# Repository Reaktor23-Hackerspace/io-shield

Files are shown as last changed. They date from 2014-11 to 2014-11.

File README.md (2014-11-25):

# IO-shield

IO-shield is a Arduino shield with 8 LED's, 8 push buttons and 2 potentiometers, designed for learning purposes.

# Pictures

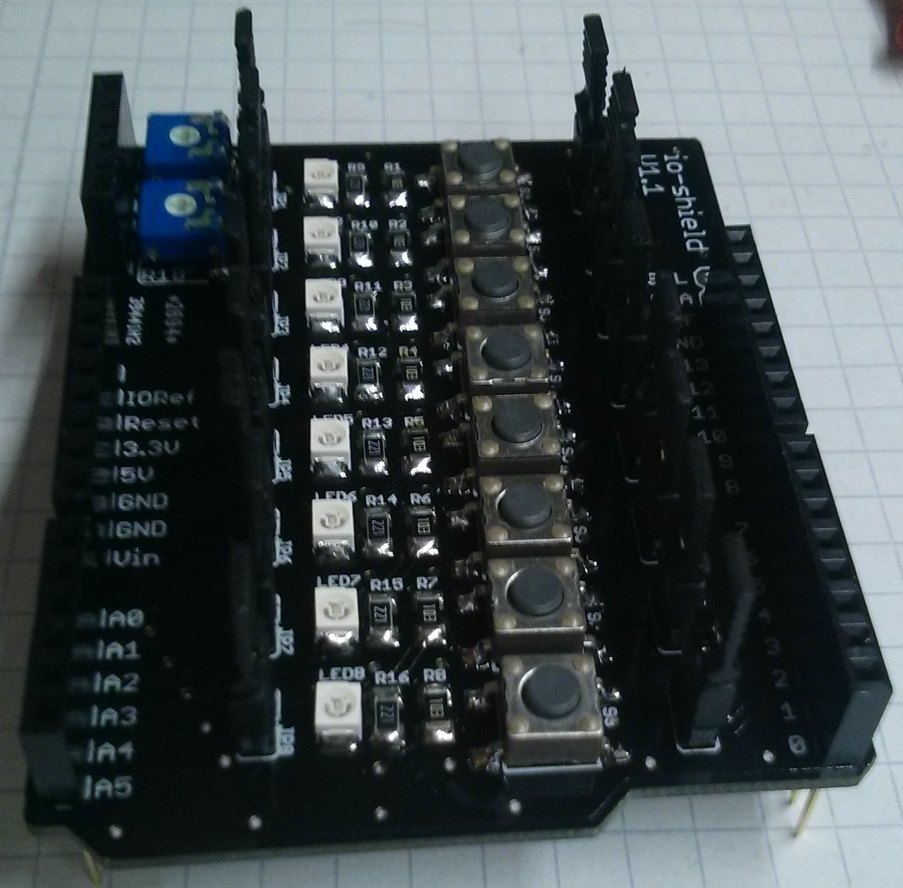
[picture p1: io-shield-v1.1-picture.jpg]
io-shield asambled


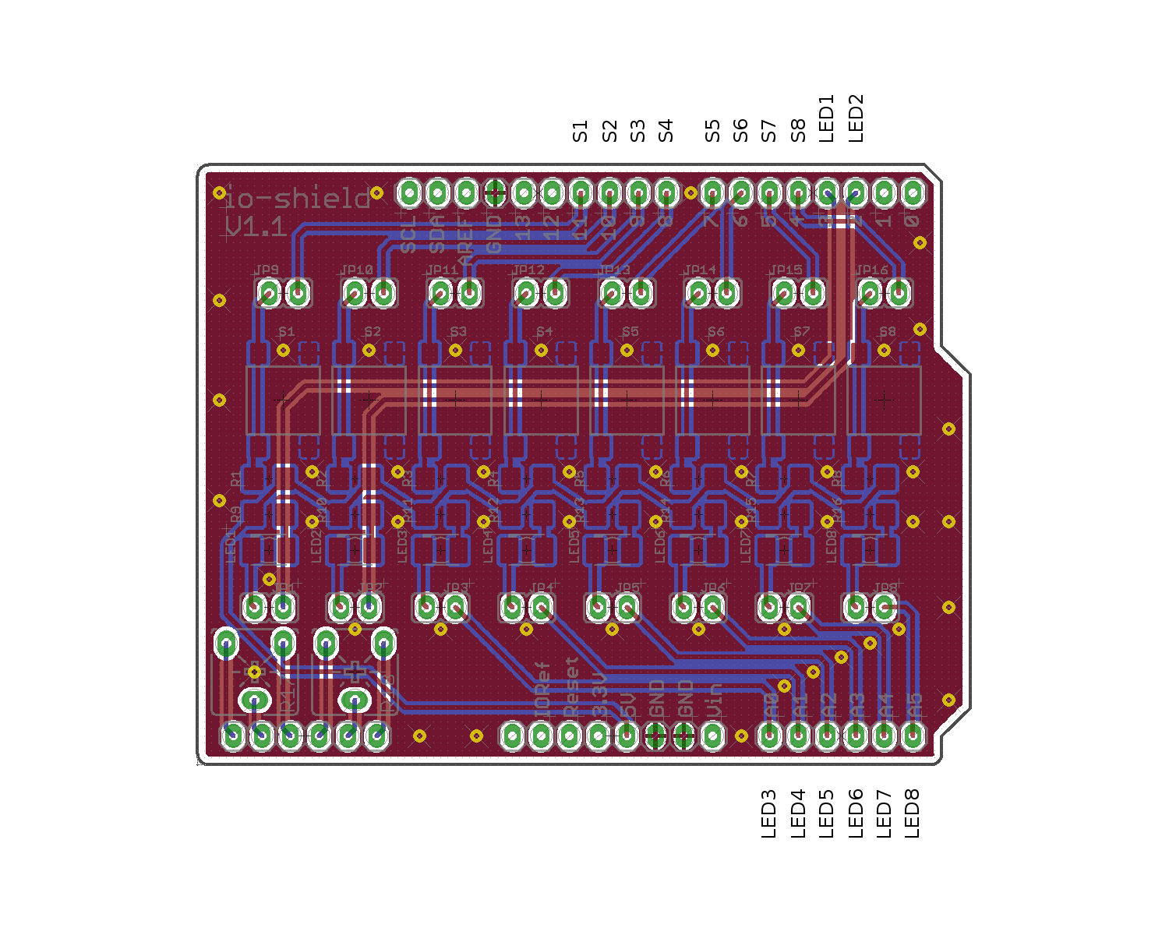
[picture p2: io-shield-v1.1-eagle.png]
io-shield eagle design


# Example program

Open and upload the example program with the Arduino IDE. Each button triggers a LED blink pattern. 
The program is for test purposes to test all components on the board (except for the 2 potentiometers).

 - Button 1 : All LED's off
 - Button 2 : All LED's on
 - Button 3 : All LED's blink
 - Button 4 : Knightrider
 - Button 5 : Chaser
 - Button 6 : VU Meter
 - Button 7 : Random blink
 - Button 8 : Bounce

Note: You need to press the buttons for about 2 seconds in the worst case to trigger a pattern change.

# Wiring

 - Push button 1 : Arduino Pin 11
 - Push button 2 : Arduino Pin 10
 - Push button 2 : Arduino Pin 9
 - Push button 4 : Arduino Pin 8
 - Push button 5 : Arduino Pin 7
 - Push button 6 : Arduino Pin 6
 - Push button 7 : Arduino Pin 5
 - Push button 8 : Arduino Pin 4

 - LED 1 : Arduino Pin 3
 - LED 2 : Arduino Pin 2
 - LED 3 : Arduino Pin A0
 - LED 4 : Arduino Pin A1
 - LED 5 : Arduino Pin A2
 - LED 6 : Arduino Pin A3
 - LED 7 : Arduino Pin A4
 - LED 8 : Arduino Pin A5

# Partlist

## Reichelt

 Part name      | Part type                                                                    | Part price (EUR) 
--------------- | ---------------------------------------------------------------------------- | ---------------- 
LED1 - LED8     | [SMD-LED 3528 BL](http://www.reichelt.de/index.html?ACTION=3;ARTICLE=46297)  | 0.25 
R9 - R16        | [SMD 1/4W 220](http://www.reichelt.de/index.html?ACTION=3;ARTICLE=18287)     | 0.103
R1 - R8         | [SMD 1/4W 10K](http://www.reichelt.de/index.html?ACTION=3;ARTICLE=18244)     | 0.103
JP1 - JP16      | [SL 1X36G 2,54](http://www.reichelt.de/index.html?ACTION=3;ARTICLE=19504)    | 0.15
                | [JUMPER 2,54GL SW](http://www.reichelt.de/index.html?ACTION=3;ARTICLE=9019)  | 0.04
S1 - S8         | [TASTER 9314](http://www.reichelt.de/index.html?ACTION=3;ARTICLE=44510)      | 0.20

## dirtypcbs.com

- PCB 20Stk.        10x10cm + DHL HongKong = 75$ (58.88 EUR)

## Ebay

- Pin Header 6x                       0.15 EUR      2 pcs. / board
- Pin header 8x                       0.15 EUR      3 pcs. / board

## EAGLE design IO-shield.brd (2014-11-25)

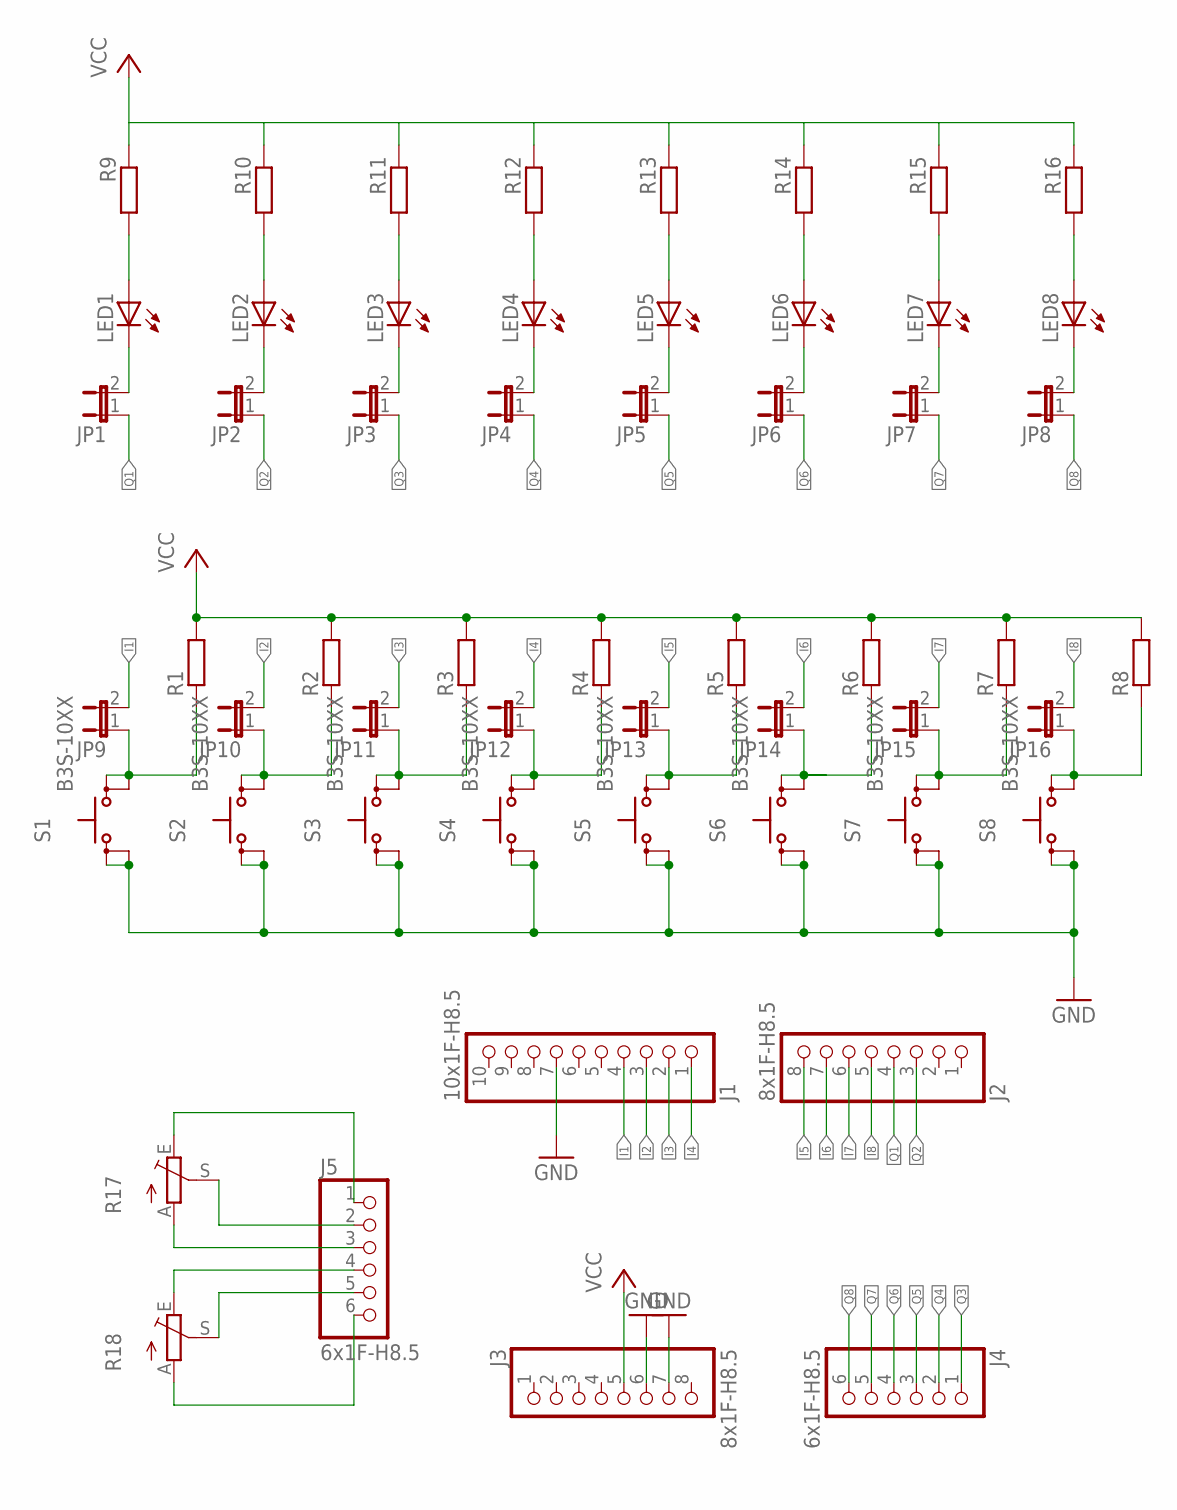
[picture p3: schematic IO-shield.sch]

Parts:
J1: 10x1F-H8.5; 1X10
J2, J3: 8x1F-H8.5; 1X08
J4, J5: 6x1F-H8.5; 1X06
JP1, JP2, JP3, JP4, JP5, JP6, JP7, JP8, JP9, JP10, JP11, JP12, JP13, JP14, JP15, JP16: JP1E; JP1
LED1, LED2, LED3, LED4, LED5, LED6, LED7, LED8: LEDKA-3528ASYC; KA-3528ASYC
R1, R2, R3, R4, R5, R6, R7, R8, R9, R10, R11, R12, R13, R14, R15, R16: R-EU_M1206; M1206
R17, R18: TRIM_EU-CA6V; CA6V
S1, S2, S3, S4, S5, S6, S7, S8: B3S-10XX

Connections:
GND: J1.7, J3.6, J3.7, S1.1, S1.2 (P1), S2.1, S2.2 (P1), S3.1, S3.2 (P1), S4.1, S4.2 (P1), S5.1, S5.2 (P1), S6.1, S6.2 (P1), S7.1, S7.2 (P1), S8.1, S8.2 (P1)
I1: J1.4, JP9.2
I2: J1.3, JP10.2
I3: J1.2, JP11.2
I4: J1.1, JP12.2
I5: J2.8, JP13.2
I6: J2.7, JP14.2
I7: J2.6, JP15.2
I8: J2.5, JP16.2
unnamed: JP1.2, LED1.C
unnamed: JP2.2, LED2.C
unnamed: JP9.1, R1.1, S1.3 (S), S1.4 (S1)
unnamed: JP10.1, R2.1, S2.3 (S), S2.4 (S1)
unnamed: JP11.1, R3.1, S3.3 (S), S3.4 (S1)
unnamed: JP12.1, R4.1, S4.3 (S), S4.4 (S1)
unnamed: JP13.1, R5.1, S5.3 (S), S5.4 (S1)
unnamed: JP14.1, R6.1, S6.3 (S), S6.4 (S1)
unnamed: LED1.A, R9.2
unnamed: LED2.A, R10.2
unnamed: LED3.A, R11.2
unnamed: LED4.A, R12.2
unnamed: LED5.A, R13.2
unnamed: LED6.A, R14.2
unnamed: LED7.A, R15.2
unnamed: LED8.A, R16.2
unnamed: JP15.1, R7.1, S7.3 (S), S7.4 (S1)
unnamed: JP16.1, R8.1, S8.3 (S), S8.4 (S1)
unnamed: JP3.2, LED3.C
unnamed: JP4.2, LED4.C
unnamed: JP5.2, LED5.C
unnamed: JP6.2, LED6.C
unnamed: JP7.2, LED7.C
unnamed: JP8.2, LED8.C
unnamed: J5.2, R17.S
unnamed: J5.1, R17.E
unnamed: J5.3, R17.A
unnamed: J5.5, R18.S
unnamed: J5.4, R18.E
unnamed: J5.6, R18.A
Q1: J2.4, JP1.1
Q2: J2.3, JP2.1
Q3: J4.1, JP3.1
Q4: J4.2, JP4.1
Q5: J4.3, JP5.1
Q6: J4.4, JP6.1
Q7: J4.5, JP7.1
Q8: J4.6, JP8.1
VCC: J3.5, R1.2, R2.2, R3.2, R4.2, R5.2, R6.2, R7.2, R8.2, R9.1, R10.1, R11.1, R12.1, R13.1, R14.1, R15.1, R16.1

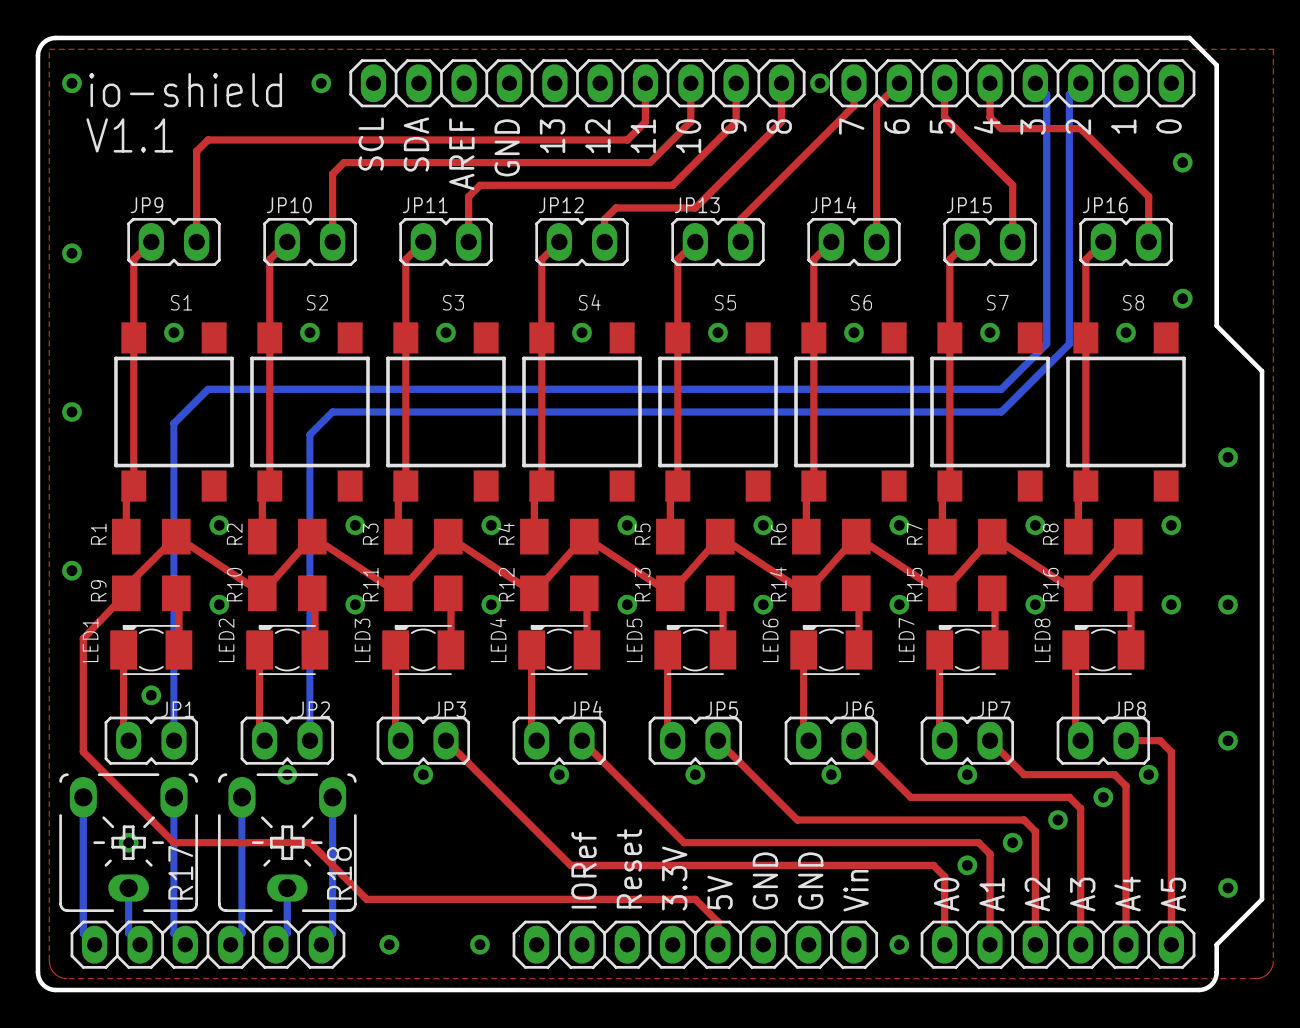
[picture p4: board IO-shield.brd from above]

Board: 2 copper layers, 68.6 x 53.3 mm, 55 parts (0 on the bottom side), 48 nets.

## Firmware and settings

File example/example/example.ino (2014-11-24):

// IO-shield V1.1
// Example code

// LED Pins
#define         LED1    3
#define         LED2    2
#define         LED3    A0
#define         LED4    A1
#define         LED5    A2
#define         LED6    A3
#define         LED7    A4
#define         LED8    A5

// Taster Pins
#define         BUTTON1    11
#define         BUTTON2    10
#define         BUTTON3    9
#define         BUTTON4    8
#define         BUTTON5    7
#define         BUTTON6    6
#define         BUTTON7    5
#define         BUTTON8    4

// Blink Modes
#define         ALL_OFF         0
#define         ALL_ON          1
#define         ALL_BLINK       2
#define         KNIGHTRIDER     3
#define         CHASER          4
#define         VUMETER         5
#define         RANDOM          6
#define         BOUNCE          7


int leds[8] = {LED1,LED2,LED3,LED4,LED5,LED6,LED7,LED8};
int buttons[8] = {BUTTON1,BUTTON2,BUTTON3,BUTTON4,BUTTON5,BUTTON6,BUTTON7,BUTTON8};

// Blink Mode
int mode=0;

void setup_leds() {

    for(int i=0; i<8; i++) {
        pinMode(leds[i],OUTPUT);
        digitalWrite(leds[i],HIGH);
    }    

}

void setup_buttons() {

    for(int i=0; i<8; i++) {
        pinMode(buttons[i],OUTPUT);
        digitalWrite(buttons[i],HIGH);
    }    

}

void all_off() {

    for(int i=0; i<8; i++) {
        digitalWrite(leds[i],HIGH);
    }    

}

void all_on() {

    for(int i=0; i<8; i++) {
        digitalWrite(leds[i],LOW);
    }    

}

void all_blink() {

    static int state = HIGH;

    if(state == HIGH) {
        state = LOW;
    } else {
        state = HIGH;
    }

    for(int i=0; i<8; i++) {
        digitalWrite(leds[i],state);
    }    

    delay(100);

}

void knightrider() {

    for(int i=0; i<4; i++) {
        all_off();
        digitalWrite(leds[i],LOW);
        digitalWrite(leds[7-i],LOW);
        delay(100);
    }    
    
    for(int i=3; i>=0; i--) {
        all_off();
        digitalWrite(leds[i],LOW);
        digitalWrite(leds[7-i],LOW);
        delay(100);
    }    

}

void chaser() {

    for(int i=0; i<8; i++) {
        all_off();
        digitalWrite(leds[i],LOW);
        delay(100);
    }

}

void vumeter() {

    for(int i=0; i<8; i++) {
        digitalWrite(leds[i],LOW);
        delay(100);
    }    

    for(int i=7; i>=0; i--) {
        digitalWrite(leds[i],HIGH);
        delay(100);
    }    

}

void blink_random() {

    int rnd = random(0xFF);
    
    all_off();

    for(int i=0; i<8; i++) {
        if(rnd & (1 << i)) {
            digitalWrite(leds[i],LOW);
        }
    }   

   delay(100); 

}

void bounce() {
    
    for(int i=0; i<8; i++) {
        all_off();
        digitalWrite(leds[i],LOW);
        delay(100);
    }

    for(int i=7; i>=0; i--) {
        all_off();
        digitalWrite(leds[i],LOW);
        delay(100);
    }

}

void setup() {

    setup_leds();
    setup_buttons();

}

void loop() {

    for(int i=0; i<8; i++) {
        if(digitalRead(buttons[i]) == LOW){
            mode = i;
            break;
        }
    }   

    switch(mode) {
        case ALL_OFF:
            all_off();
        break;
        case ALL_ON:
            all_on();
        break;
        case ALL_BLINK:
            all_blink();
        break;
        case KNIGHTRIDER:
            knightrider();
        break;
        case CHASER:
            chaser();
        break;
        case VUMETER:
            vumeter();
        break;
        case RANDOM:
            blink_random();
        break;
        case BOUNCE:
            bounce();
        break;
    
    }

}

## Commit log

2014-10-08 initial release
    [IO-shield.brd, IO-shield.sch]
2014-10-29 extended shield with jumpers, added part list and picture
    [IO-shield.brd, IO-shield.sch]
2014-11-06 changed position of the jumpers
    [IO-shield.brd]
2014-11-06 added 2 potis and header
    [IO-shield.brd, IO-shield.sch]
2014-11-25 updated README, added eagle layout picture, fixed board silkscreen
    [IO-shield.brd]
